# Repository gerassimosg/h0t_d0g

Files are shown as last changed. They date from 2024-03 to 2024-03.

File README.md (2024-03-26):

h0t_d0g is a state-of-the-art device that solves a pressing issue in our society: hot dog detection. Using a Raspberry Pi 3B+, a Raspberry Pi HQ camera module, and a pretrained convolutional neural network called [YOLOv8](https://github.com/ultralytics/ultralytics/tree/main?tab=readme-ov-file), we have been able to create a device that can tell you if an object is:
  1. A hog dog
  2. NOT a hot dog

The design also features a custom Raspberry Pi hat that includes a button for triggering the camera module, and an OLED screen, LEDs, buzzers, and vibrational motors for indication.

Yes, we are aware this device is similar to a bit from [Silicon Valley](https://www.youtube.com/watch?v=ACmydtFDTGs&ab_channel=HBO). Consider this another beautiful example of [simultaneous invention](https://en.wikipedia.org/wiki/Multiple_discovery). 

The setup for the scripts is unfortunately not very straightforward, so we recommend just using a [copy of our Raspberry Pi image](https://drive.google.com/file/d/1S39A5wuWlGqCmSLLNGbD2eGSzYuv83wq/view?usp=sharing) if you would like to demo the device yourself.

A demo of our device can be seen on YouTube [here](https://youtu.be/dtBpYx1jwMI).

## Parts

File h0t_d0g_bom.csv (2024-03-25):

Line Item | Description | Comments | Link
1 | Raspberry Pi 3B+ | NOT tested with other Pi models
2 | 32 GB Micro SD Card | UNSURE if a smalled SD card will work when burning image
3 | h0t_d0g PI Shield
4 | OLED Screen | OLED screen was NOT installed by fab house | https://www.amazon.com/dp/B072Q2X2LL?psc=1&ref=ppx_yo2ov_dt_b_product_details
5 | Raspberry Pi HQ Camera Module |  | https://www.amazon.com/dp/B08LHJR3K4?psc=1&ref=ppx_yo2ov_dt_b_product_details
6 | Flex Tripod |  | https://www.amazon.com/GripTight-ONE-GorillaPod-Stand-Smartphones/dp/B01NGTBA3E?th=1
7 | Brass M2.5 Hardware | For Pi mounting | https://www.amazon.com/dp/B07KM27KC6?psc=1&ref=ppx_yo2ov_dt_b_product_details
8 | Brass M2 Hardware | For OLED screen mounting | https://www.amazon.com/Litorange-Standoff-Threaded-Motherboard-Assortment/dp/B07PDQ7DVS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
9 | 6mm 3MP Wide Angle Lens |  | https://www.adafruit.com/product/4563
10 | Black Nylon M2.5 Hardware | For camera mounting | https://www.adafruit.com/product/3299
11 | Mounting Plate for HQ Camera | For camera mounting | https://www.adafruit.com/product/5026
12 | Type A to Micro USB Cable
13 | USB Power Bank

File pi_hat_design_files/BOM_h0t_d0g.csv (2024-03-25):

ID | Name | Designator | Footprint | Quantity | Manufacturer Part | Manufacturer | Supplier | Supplier Part | Price
1 | 0Ω | R13,R14,R15,R16,R17,R19,R18,R45,R35,R40,R59,R60,R5,R6,R7,R8,R29,R30,R32,R33,R50,R51,R56,R1,R2,R3,R4 | R0402 | 27 | 0402WGF0000TCE | UNI-ROYAL(厚声) | LCSC | C17168 | 0.001
2 | 47kΩ | R20,R46,R36,R34,R39,R41,R44,R49,R54,R38,R42,R47,R52,R55,R58 | R0402 | 15 | 0402WGF4702TCE | UNI-ROYAL(厚声) | LCSC | C25792 | 0.001
3 | AD5263BRUZ50-REEL7 | U2 | TSSOP-24_L7.8-W4.4-P0.65-LS6.4-BL | 1 | AD5263BRUZ50-REEL7 | ADI(亚德诺) | LCSC | C649465 | 12.389
4 | 100Ω | R28,R10,R11,R12,R22,R23,R24,R26,R27 | R0805 | 9 | 0805W8F1000T5E | UNI-ROYAL(厚声) | LCSC | C17408 | 0.002
5 | 150Ω | R9,R21,R25 | R0805 | 3 | 0805W8F1500T5E | UNI-ROYAL(厚声) | LCSC | C17471 | 0.002
6 | Z3OC1T8219731 | M1,M2 | VIBRATING-MOTOR-SMD_3P-C9900001680 | 2 | Z3OC1T8219731 | KOTL(金龙机电) | LCSC | C2894731 | 1.136
7 | ZX-PM2.54-2-20PY | J1 | HDR-TH_40P-P2.54-V-F-R2-C20-S2.54 | 1 | ZX-PM2.54-2-20PY | Megastar(兆星) | LCSC | C7499354 | 0.339
8 | 15nF | C20,C22 | C0402 | 2 | CC0402KRX7R9BB153 | YAGEO(国巨) | LCSC | C114405 | 0.003
9 | MIC1557YM5-TR | U5,U3,U4 | SOT-23-5_L3.0-W1.7-P0.95-LS2.8-BL | 3 | MIC1557YM5-TR | MICROCHIP(美国微芯) | LCSC | C144169 | 2.27
10 | 39nF | C19 | C0402 | 1 | GCM155R71E393KA55D | muRata(村田) | LCSC | C408119 | 0.007
11 | 1uF | C5,C12,C6,C7,C13,C14,C15,C16,C24,C23,C10,C11 | C0402 | 12 | CL05A105KO5NNNC | SAMSUNG(三星) | LCSC | C29266 | 0.002
12 | K14 | D1,D2,D3,D4,D5 | SOD-123FL_L2.7-W1.8-LS3.7-RD | 5 | K14 | DOWO(东沃) | LCSC | C2844079 | 0.015
13 | 10uF | C17,C18,C3,C4 | C0603 | 4 | CL10A106MO8NQNC | SAMSUNG(三星) | LCSC | C92487 | 0.014
14 | 3.3nF | C21 | C0402 | 1 | CC0402KRX7R9BB332 | YAGEO(国巨) | LCSC | C107028 | 0.001
15 | 1kΩ | R31,R37,R43,R48,R53 | R0402 | 5 | RC0402FR-071KL | YAGEO(国巨) | LCSC | C106235 | 0.001
16 | 47uF | C1,C2 | C1206 | 2 | 1206X476M160NT | FH(风华) | LCSC | C172351 | 0.211
17 | SS8050 | Q1,Q2,Q3,Q4,Q5 | SOT-23-3_L2.9-W1.3-P1.90-LS2.4-BR | 5 | SS8050 | CJ(江苏长电/长晶) | LCSC | C2150 | 0.015
18 | H7227-1 | U7 | SOT-89-3_L4.5-W2.5-P1.50-LS4.2-BR | 1 | H7227-1 | Siproin(上海矽朋) | LCSC | C277846 | 0.112
19 | 47uF | C8,C9 | C0805 | 2 | C2012X5R1A476MTJ00E | TDK | LCSC | C76636 | 0.194
20 | TJ-S5050UG3W5TLCRGBTW-A5 | LED3,LED1,LED2 | LED-ARRAY-SMD_8P-L5.0-W5.0-TL-RD | 3 | TJ-S5050UG3W5TLCRGBTW-A5 | TOGIALED(统佳) | LCSC | C440461 | 0.112
21 | BTSA-N-P-1 | SW1 | SW-TH_BTSA-X-P-1 | 1 | BTSA-N-P-1 | ROCPU Switches(台普) | LCSC | C2693625 | 0.208
22 | TLC555DRG | U8 | SOIC-8_L4.9-W3.9-P1.27-LS6.0-BL | 1 | TLC555DRG | HGC(深圳汉芯) | LCSC | C5145349 | 0.15
23 | 1MΩ | R57 | R0402 | 1 | 0402WGF1004TCE | UNI-ROYAL(厚声) | LCSC | C26083 | 0.001
24 | YS-MBZ9042C05R42 | BUZZER1,BUZZER2,BUZZER3 | BUZ-TH_BD9.0-P4.00-D1.0-FD | 3 | YS-MBZ9042C05R42 | Fengming | LCSC | C409837 | 0.22
25 | HS96L03W2C03 | OLED1 | OLED-TH_L27.8-W27.2-P2.54_C9900033791 | 1 | HS96L03W2C03 | HS(汉昇) | LCSC | C5248080 | 1.887
26 | PCA9635PW,118 | U1 | TSSOP-28_L9.7-W4.4-P0.65-LS6.4-BL | 1 | PCA9635PW,118 | NXP(恩智浦) | LCSC | C110795 | 1.914
27 | SN74LVC2G34DCKR | U6 | SOT-363_L2.0-W1.3-P0.65-LS2.1-BR | 1 | SN74LVC2G34DCKR | TI(德州仪器) | LCSC | C14461 | 0.199

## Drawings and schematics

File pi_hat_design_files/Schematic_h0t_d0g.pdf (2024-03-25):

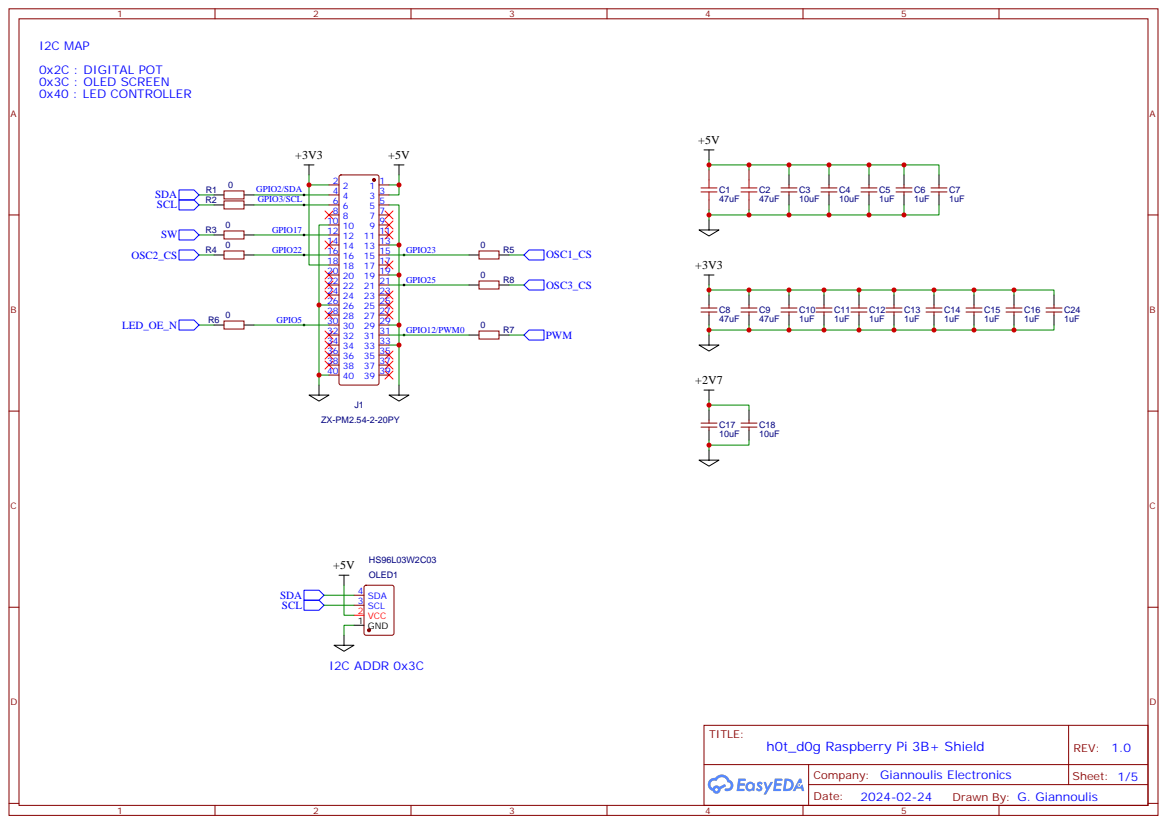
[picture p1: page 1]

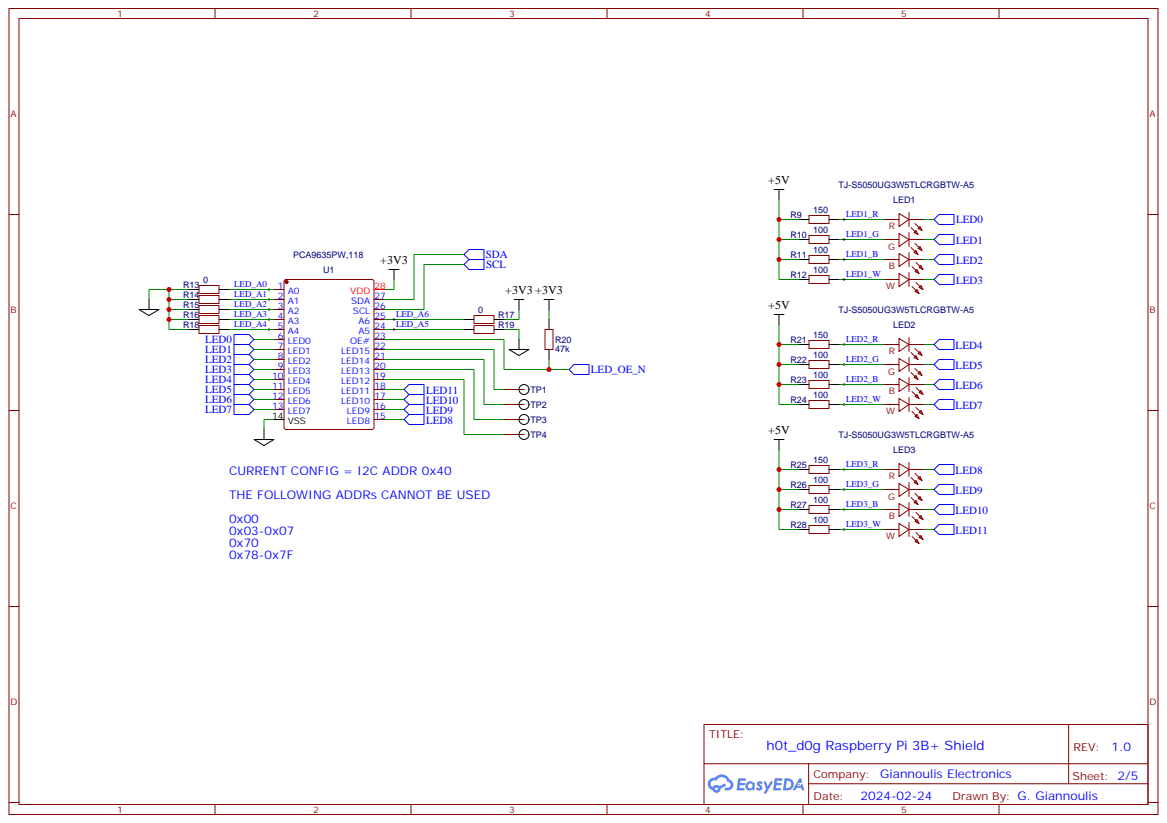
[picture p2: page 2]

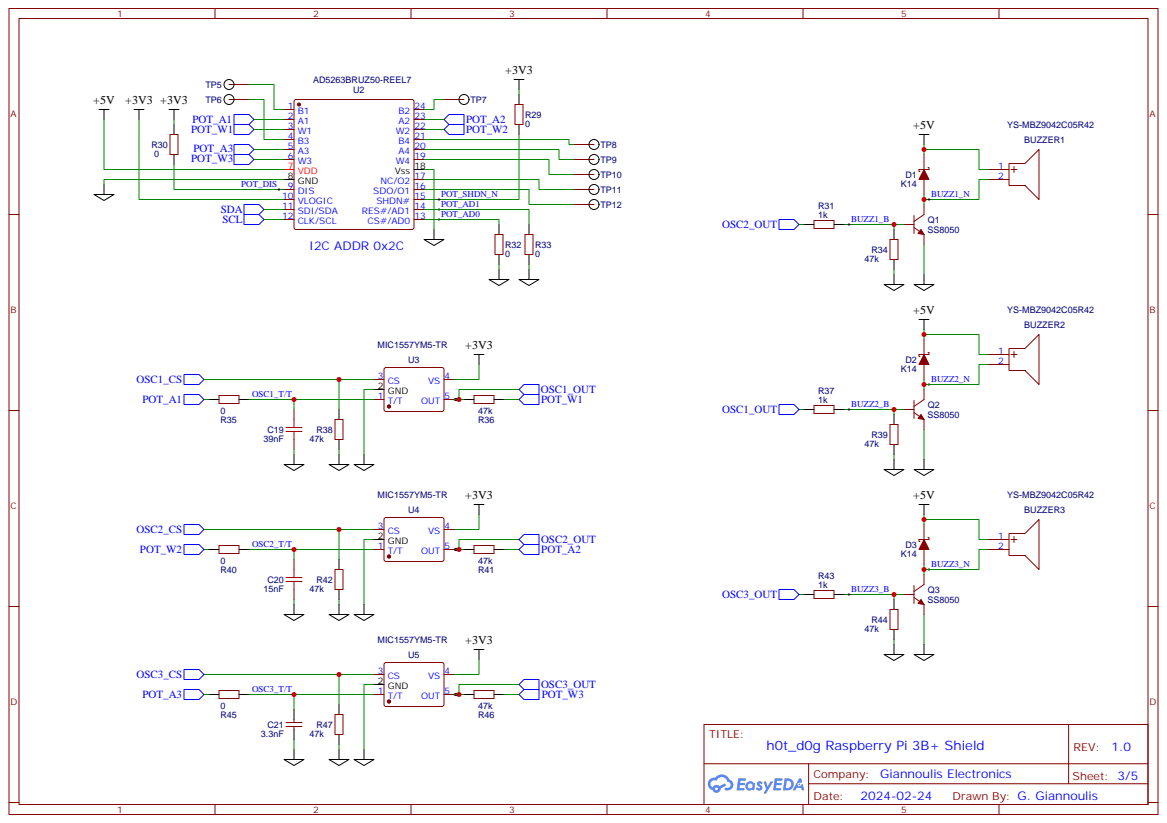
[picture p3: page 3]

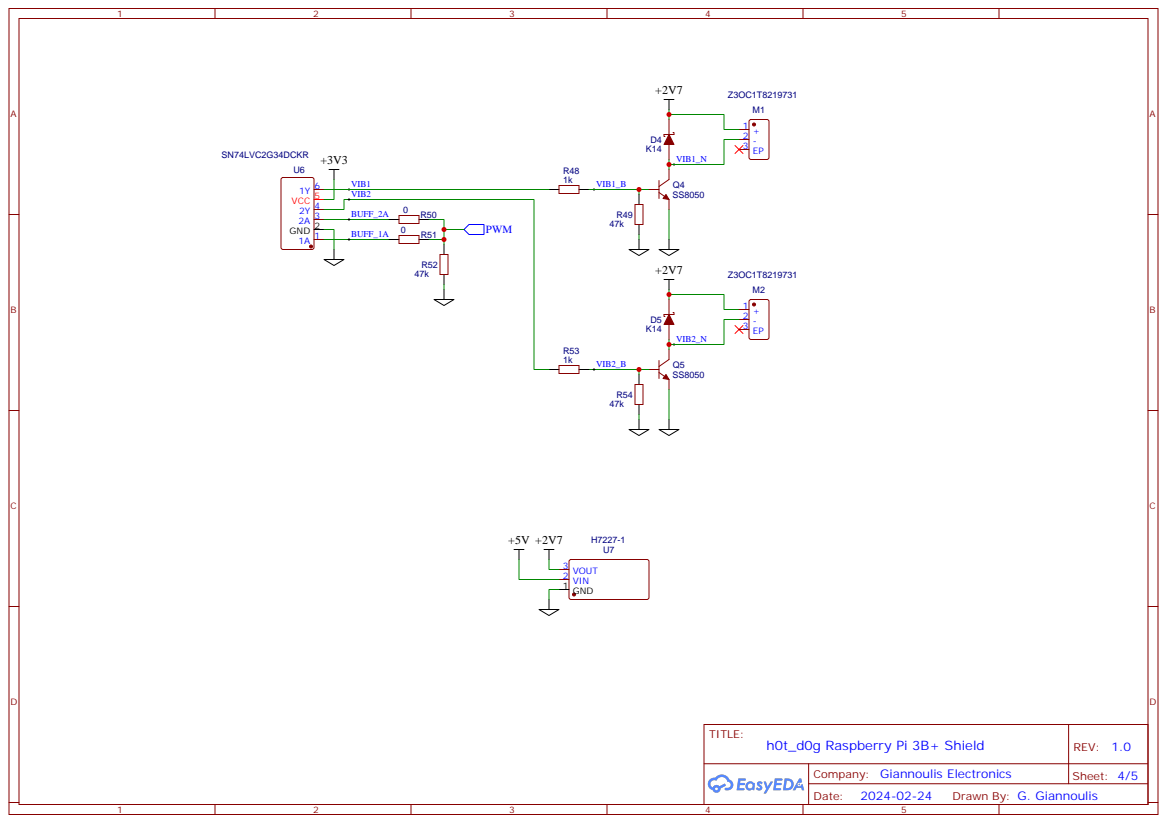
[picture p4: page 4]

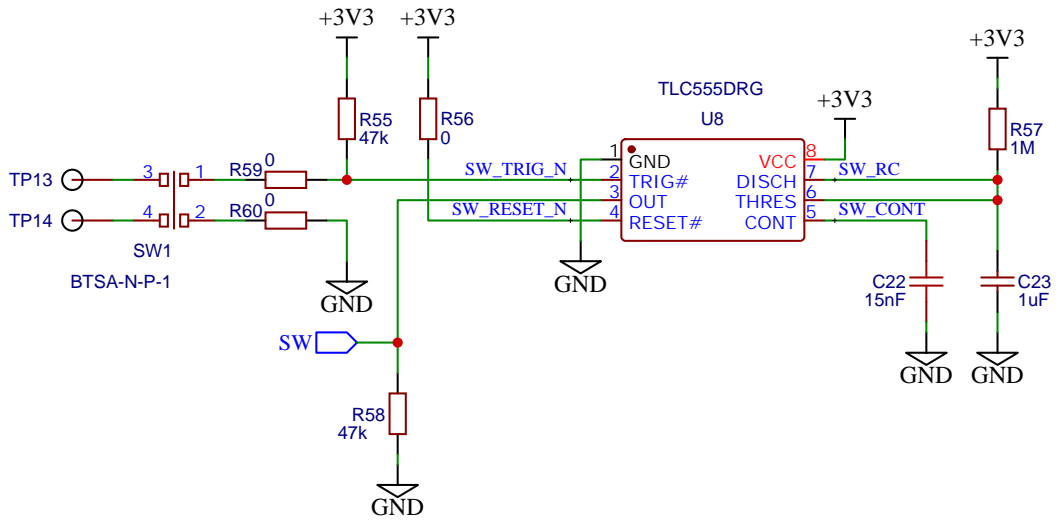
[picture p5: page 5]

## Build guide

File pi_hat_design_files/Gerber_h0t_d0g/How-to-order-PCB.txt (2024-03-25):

How to Order PCB

Please refer to:
https://docs.easyeda.com/en/PCB/Order-PCB

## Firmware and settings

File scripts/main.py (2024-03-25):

import os
import sys
import time
import RPi.GPIO as GPIO

sw=17
init="bash /home/jer/h0t_d0g/init.sh"
ready="bash /home/jer/h0t_d0g/ready.sh"
calc="bash /home/jer/h0t_d0g/calc.sh"
pic="bash /home/jer/h0t_d0g/pic.sh"
take_pic="rpicam-jpeg -t 2000 -o /home/jer/h0t_d0g/pic.jpg"
pic_test="/home/jer/h0t_d0g/pic.jpg"
pass_test="bash /home/jer/h0t_d0g/pass.sh"
fail_test="bash /home/jer/h0t_d0g/fail.sh"
model_test="/home/jer/h0t_d0g/yolov8n.pt"
results_test="/home/jer/h0t_d0g/yolov8n.pt"

GPIO.setwarnings(False)
GPIO.setmode(GPIO.BCM)
GPIO.setup(sw, GPIO.IN)

def wait_for_switch():
	while not (GPIO.input(sw)):
		time.sleep(0.1)

os.system(init)

from ultralytics import YOLO
model=YOLO(model_test)

os.system(ready)

while True:
	results_flag=False

	wait_for_switch()
	os.system(pic)
	os.system(take_pic)

	os.system(calc)
	results=model(pic_test, conf=0.5)
	model_names=results[0].names
	model_class=results[0].boxes.cls

	for i in range(len(model_class)):
		if model_names[int(model_class[i])] == 'hot dog':
			results_flag=True
			break

	if results_flag:
		os.system(pass_test)
	else:
		os.system(fail_test)

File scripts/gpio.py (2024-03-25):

import sys
import time
import RPi.GPIO as GPIO

leds=5
osc1=23
osc2=22
osc3=25
pwm=12
pwm_freq=10
pwm_duty=80

GPIO.setwarnings(False)
GPIO.setmode(GPIO.BCM)

if len(sys.argv) > 1:
	if sys.argv[1] == 'leds_on':
		GPIO.setup(leds, GPIO.OUT)
		GPIO.output(leds, GPIO.LOW)
	elif sys.argv[1] == 'leds_off':
		GPIO.setup(leds, GPIO.OUT)
		GPIO.output(leds, GPIO.HIGH)
	elif sys.argv[1] == 'osc1_on':
		GPIO.setup(osc1, GPIO.OUT)
		GPIO.output(osc1, GPIO.HIGH)
	elif sys.argv[1] == 'osc1_off':
		GPIO.setup(osc1, GPIO.OUT)
		GPIO.output(osc1, GPIO.LOW)
	elif sys.argv[1] == 'osc2_on':
		GPIO.setup(osc2, GPIO.OUT)
		GPIO.output(osc2, GPIO.HIGH)
	elif sys.argv[1] == 'osc2_off':
		GPIO.setup(osc2, GPIO.OUT)
		GPIO.output(osc2, GPIO.LOW)
	elif sys.argv[1] == 'osc3_on':
		GPIO.setup(osc3, GPIO.OUT)
		GPIO.output(osc3, GPIO.HIGH)
	elif sys.argv[1] == 'osc3_off':
		GPIO.setup(osc3, GPIO.OUT)
		GPIO.output(osc3, GPIO.LOW)
	elif sys.argv[1] == 'vib_on':
		GPIO.setup(pwm, GPIO.OUT)
		vib = GPIO.PWM(pwm, pwm_freq)
		vib.start(pwm_duty)
	elif sys.argv[1] == 'vib_off':
		GPIO.setup(pwm, GPIO.OUT)
		GPIO.output(pwm, GPIO.LOW)
	else:
		print("INVALID ARGUMENT")
else:
	print("INVALID ARGUMENT")
